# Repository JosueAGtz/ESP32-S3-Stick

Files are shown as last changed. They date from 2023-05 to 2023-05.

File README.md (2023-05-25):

# ESP32-S3 Stick

ESP32-S3 is a dual-core XTensa LX7 MCU, capable of running at 240 MHz. Apart from its 512 KB of internal SRAM, it also comes with integrated 2.4 GHz, 802.11 b/g/n Wi-Fi and Bluetooth 5 (LE) connectivity that provides long-range support. It has 45 programmable GPIOs and supports a rich set of peripherals.

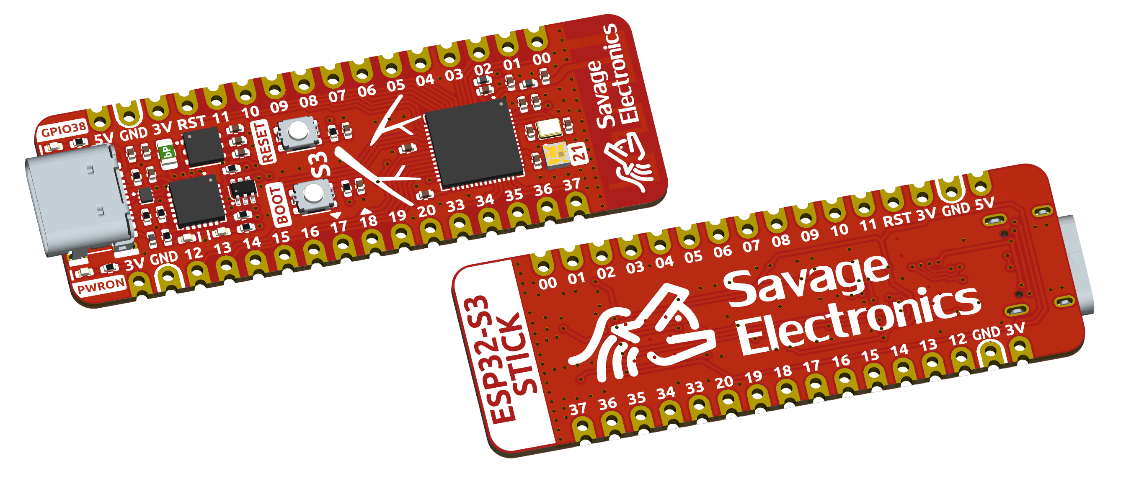
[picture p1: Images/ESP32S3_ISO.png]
ESP32S3_Board


## ESP32-S3 Stick Pinout

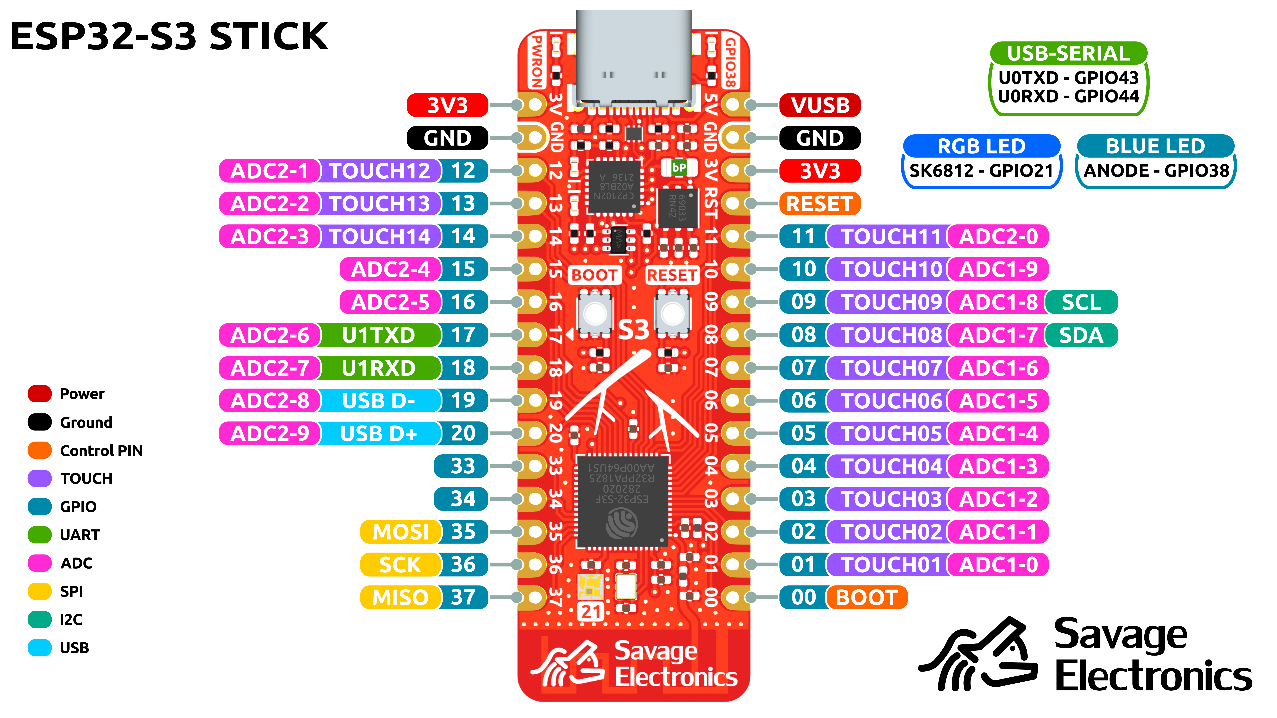
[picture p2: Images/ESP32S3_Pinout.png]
ESP32S3_Pinout


## ESP32-S3 Stick Features

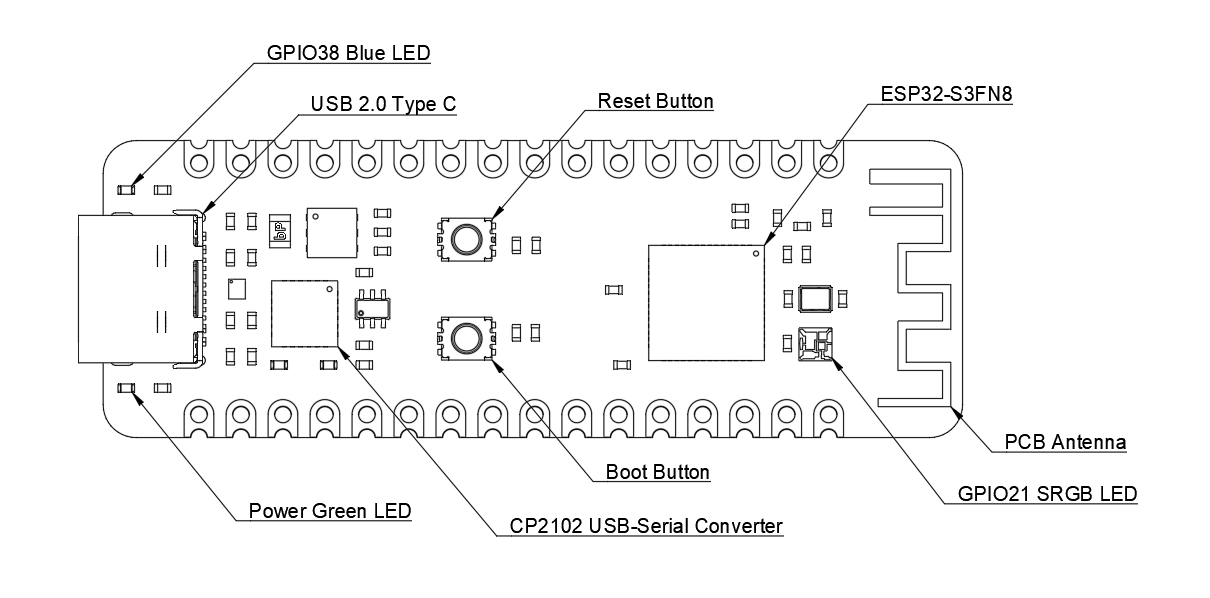
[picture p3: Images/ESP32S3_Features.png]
ESP32S3_Features


## ESP32-S3 Stick Dimmensions

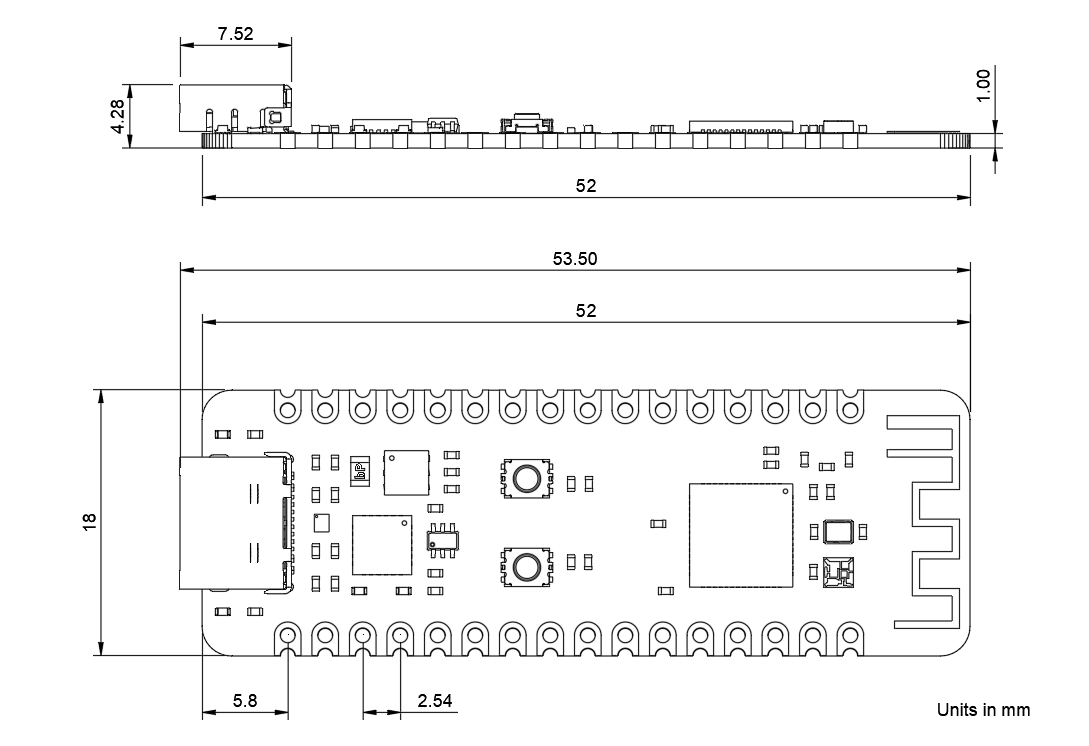
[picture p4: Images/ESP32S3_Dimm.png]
ESP32S3_Dimm


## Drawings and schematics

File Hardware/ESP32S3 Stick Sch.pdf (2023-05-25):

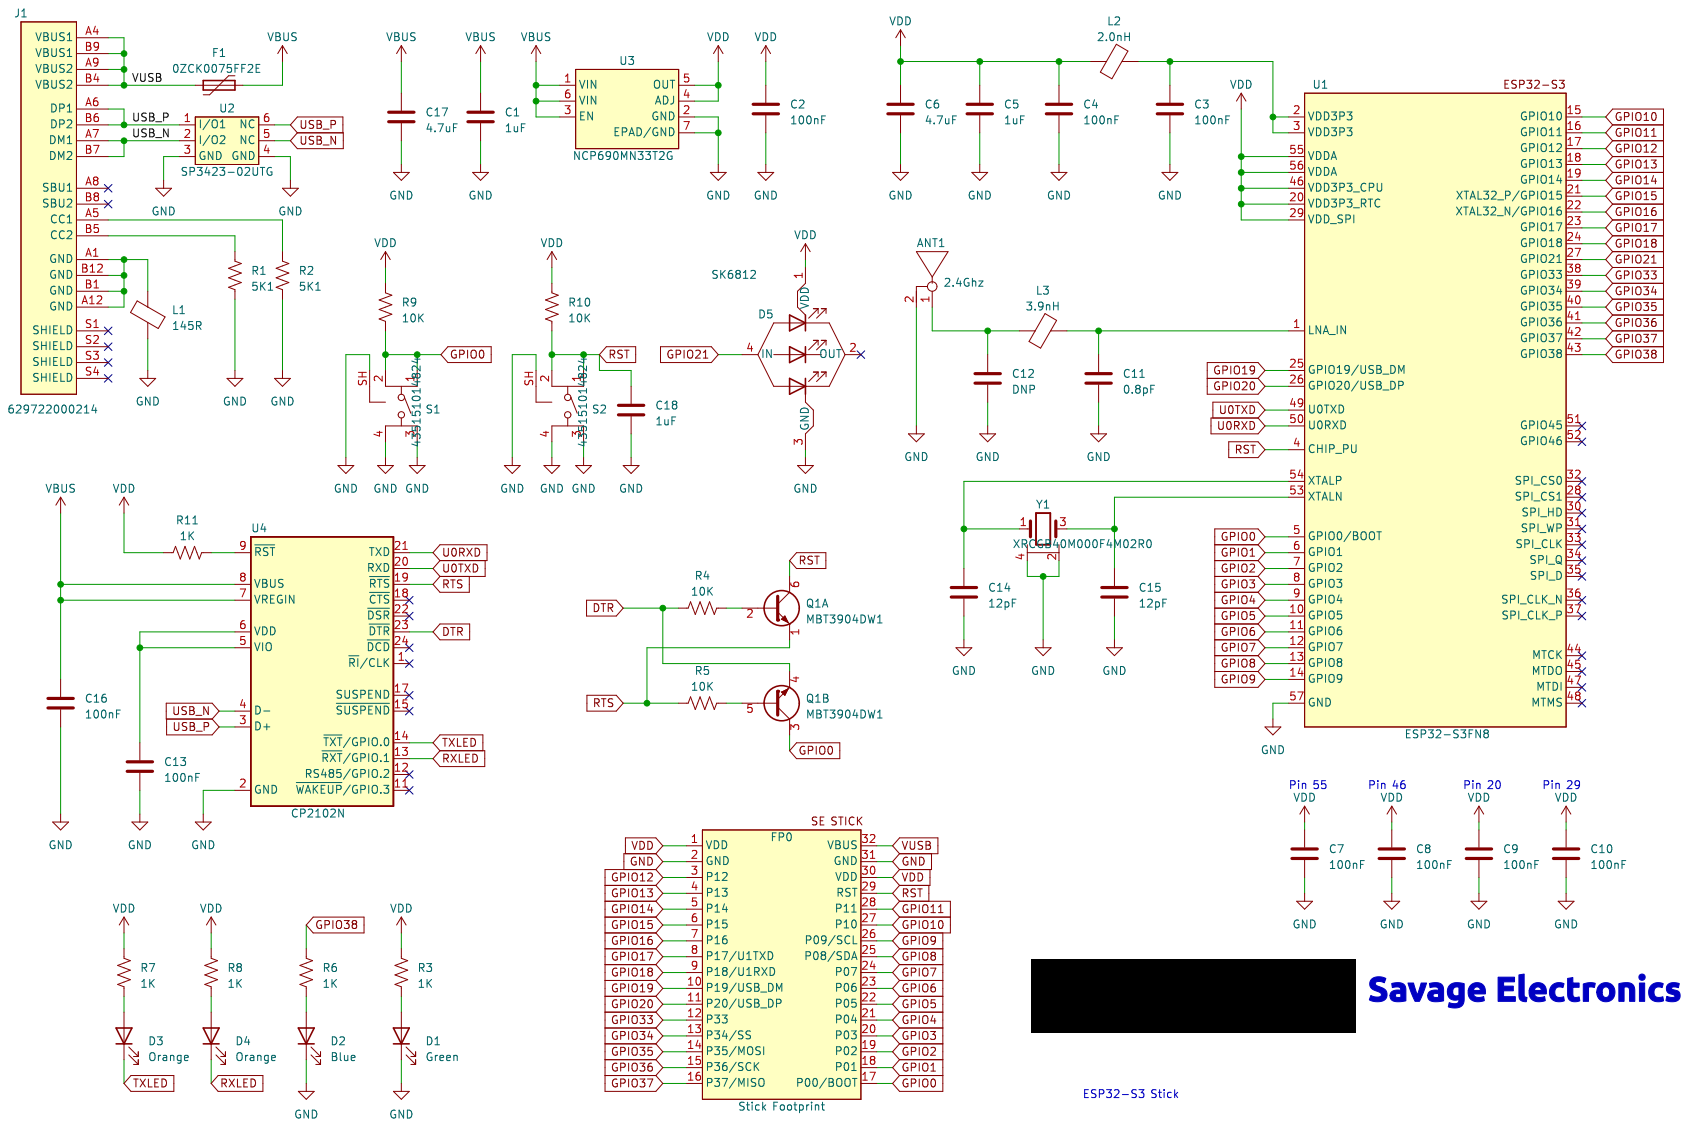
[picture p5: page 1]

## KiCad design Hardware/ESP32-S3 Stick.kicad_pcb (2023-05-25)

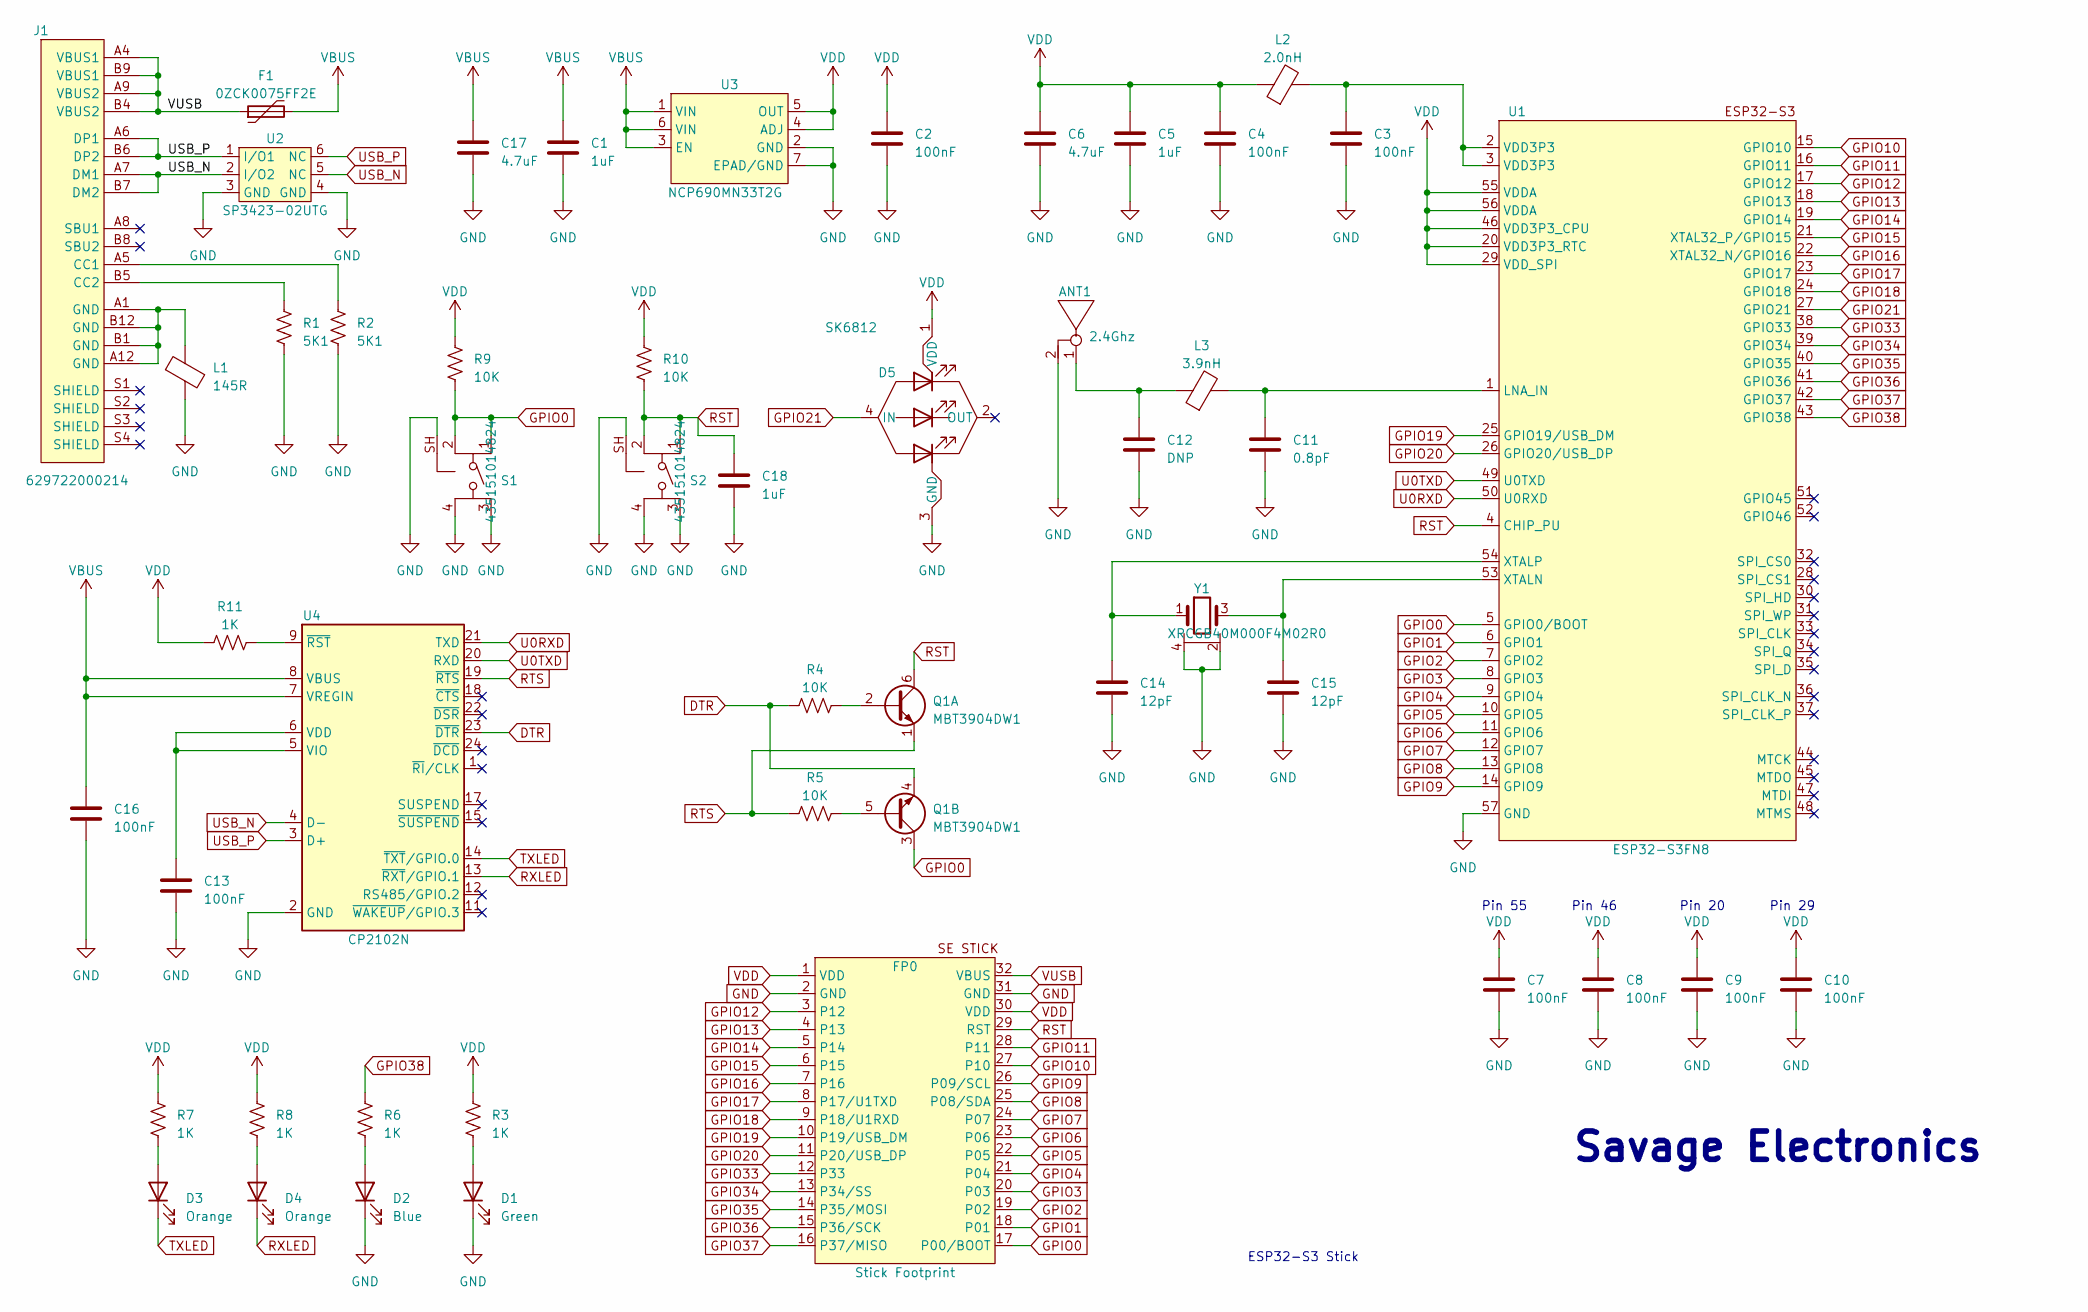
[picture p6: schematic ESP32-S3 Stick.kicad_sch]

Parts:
ANT1: 2.4Ghz; PCB_Ant24
C1, C5, C18: 1uF; C_0402_1005Metric
C2, C3, C4, C7, C8, C9, C10, C13, C16: 100nF; C_0402_1005Metric
C6, C17: 4.7uF; C_0402_1005Metric
C11: 0.8pF; C_0402_1005Metric
C12: DNP; C_0402_1005Metric
C14, C15: 12pF; C_0402_1005Metric
D1: Green; 0402LED
D2: Blue; 0402LED
D3, D4: Orange; 0402LED
D5: SK6812; SK6812_2X2mm
F1: 0ZCK0075FF2E; Fuse_0805_2012Metric
FP0: Stick Footprint; Stick
J1: 629722000214; USBC 2.0
L1: 145R; L_0402_1005Metric
L2: 2.0nH; L_0402_1005Metric
L3: 3.9nH; L_0402_1005Metric
Q1: MBT3904DW1; SC70_6P
R1, R2: 5K1; R_0402_1005Metric
R3, R6, R7, R8, R11: 1K; R_0402_1005Metric
R4, R5, R9, R10: 10K; R_0402_1005Metric
S1, S2: 435151014824
U1: ESP32-S3FN8; QFN-56-1EP_7x7mm_P0.4mm_EP4x4mm_ThermalVias_ ESP32-S3
U2: SP3423-02UTG
U3: NCP690MN33T2G; DFN6_P1MM_EP
U4: CP2102N; QFN24_4X4MM_P05_EP26
Y1: XRCGB40M000F4M02R0; SMD_4PADS_20X16

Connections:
DTR: Q1.4 (E2), R4.1, U4.23 (~DTR)
GND: ANT1.2, C1.2, C2.2, C3.2, C4.2, C5.2, C6.2, C7.2, C8.2, C9.2, C10.2, C11.2, C12.2, C13.2, C14.2, C15.2, C16.2, C17.2, C18.2, D1.1 (K), D2.1 (K), D5.3 (GND), FP0.2 (GND), FP0.31 (GND), L1.2, R1.2, R2.2, S1.3, S1.4, S1.SH, S2.3, S2.4, S2.SH, U1.57 (GND), U2.3 (GND), U2.4 (GND), U3.2 (GND), U3.7 (EPAD/GND), U4.2 (GND), U4.25 (GND), Y1.2, Y1.4
GPIO0: FP0.17 (P00/BOOT), Q1.3 (C2), R9.2, S1.1, S1.2, U1.5 (GPIO0/BOOT)
GPIO1: FP0.18 (P01), U1.6 (GPIO1)
GPIO2: FP0.19 (P02), U1.7 (GPIO2)
GPIO3: FP0.20 (P03), U1.8 (GPIO3)
GPIO4: FP0.21 (P04), U1.9 (GPIO4)
GPIO5: FP0.22 (P05), U1.10 (GPIO5)
GPIO6: FP0.23 (P06), U1.11 (GPIO6)
GPIO7: FP0.24 (P07), U1.12 (GPIO7)
GPIO8: FP0.25 (P08/SDA), U1.13 (GPIO8)
GPIO9: FP0.26 (P09/SCL), U1.14 (GPIO9)
GPIO10: FP0.27 (P10), U1.15 (GPIO10)
GPIO11: FP0.28 (P11), U1.16 (GPIO11)
GPIO12: FP0.3 (P12), U1.17 (GPIO12)
GPIO13: FP0.4 (P13), U1.18 (GPIO13)
GPIO14: FP0.5 (P14), U1.19 (GPIO14)
GPIO15: FP0.6 (P15), U1.21 (XTAL32_P/GPIO15)
GPIO16: FP0.7 (P16), U1.22 (XTAL32_N/GPIO16)
GPIO17: FP0.8 (P17/U1TXD), U1.23 (GPIO17)
GPIO18: FP0.9 (P18/U1RXD), U1.24 (GPIO18)
GPIO19: FP0.10 (P19/USB_DM), U1.25 (GPIO19/USB_DM)
GPIO20: FP0.11 (P20/USB_DP), U1.26 (GPIO20/USB_DP)
GPIO21: D5.4 (IN), U1.27 (GPIO21)
GPIO33: FP0.12 (P33), U1.38 (GPIO33)
GPIO34: FP0.13 (P34/SS), U1.39 (GPIO34)
GPIO35: FP0.14 (P35/MOSI), U1.40 (GPIO35)
GPIO36: FP0.15 (P36/SCK), U1.41 (GPIO36)
GPIO37: FP0.16 (P37/MISO), U1.42 (GPIO37)
GPIO38: R6.1, U1.43 (GPIO38)
unnamed: ANT1.1, C12.1, L3.1
unnamed: C3.1, L2.2, U1.2 (VDD3P3), U1.3 (VDD3P3)
unnamed: D1.2 (A), R3.2
unnamed: D2.2 (A), R6.2
unnamed: D3.2 (A), R7.2
unnamed: D4.2 (A), R8.2
unnamed: J1.A5 (CC1), R2.1
unnamed: J1.B5 (CC2), R1.1
unnamed: J1.A1 (GND), J1.A12 (GND), J1.B1 (GND), J1.B12 (GND), L1.1
unnamed: Q1.2 (B1), R4.2
unnamed: Q1.5 (B2), R5.2
unnamed: C11.1, L3.2, U1.1 (LNA_IN)
unnamed: C15.1, U1.53 (XTALN), Y1.3
unnamed: C14.1, U1.54 (XTALP), Y1.1
unnamed: C13.1, U4.5 (VIO), U4.6 (VDD)
unnamed: R11.2, U4.9 (~RST)
RST: C18.1, FP0.29 (RST), Q1.6 (C1), R10.2, S2.1, S2.2, U1.4 (CHIP_PU)
RTS: Q1.1 (E1), R5.1, U4.19 (~RTS)
RXLED: D4.1 (K), U4.13 (~RXT/GPIO.1)
TXLED: D3.1 (K), U4.14 (~TXT/GPIO.0)
U0RXD: U1.50 (U0RXD), U4.21 (TXD)
U0TXD: U1.49 (U0TXD), U4.20 (RXD)
USB_N: J1.A7 (DM1), J1.B7 (DM2), U2.2 (I/O2), U2.5 (NC), U4.4 (D-)
USB_P: J1.A6 (DP1), J1.B6 (DP2), U2.1 (I/O1), U2.6 (NC), U4.3 (D+)
VBUS: C1.1, C16.1, C17.1, F1.2, U3.1 (VIN), U3.3 (EN), U3.6 (VIN), U4.7 (VREGIN), U4.8 (VBUS)
VDD: C2.1, C4.1, C5.1, C6.1, C7.1, C8.1, C9.1, C10.1, D5.1 (VDD), FP0.1 (VDD), FP0.30 (VDD), L2.1, R3.1, R7.1, R8.1, R9.1, R10.1, R11.1, U1.20 (VDD3P3_RTC), U1.29 (VDD_SPI), U1.46 (VDD3P3_CPU), U1.55 (VDDA), U1.56 (VDDA), U3.4 (ADJ), U3.5 (OUT)
VUSB: F1.1, FP0.32 (VBUS), J1.A4 (VBUS1), J1.A9 (VBUS2), J1.B4 (VBUS2), J1.B9 (VBUS1)

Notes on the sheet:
Pin 55
Pin 29
ESP32-S3 Stick
Pin 20
Savage Electronics
Pin 46

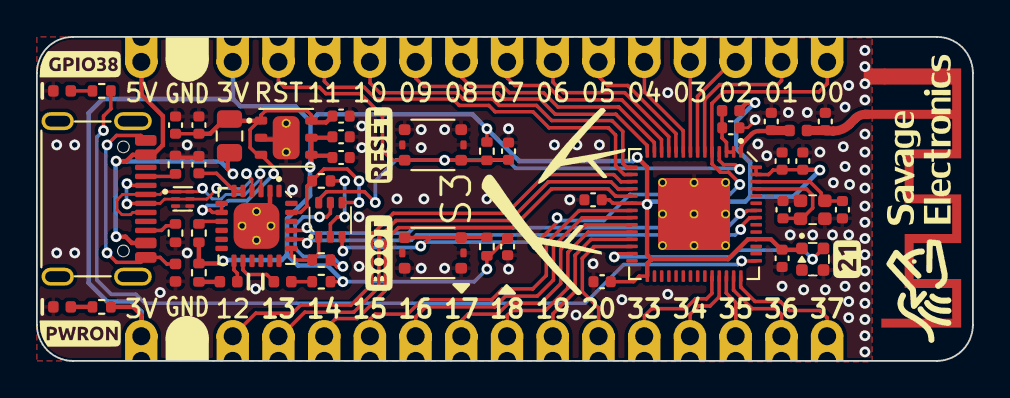
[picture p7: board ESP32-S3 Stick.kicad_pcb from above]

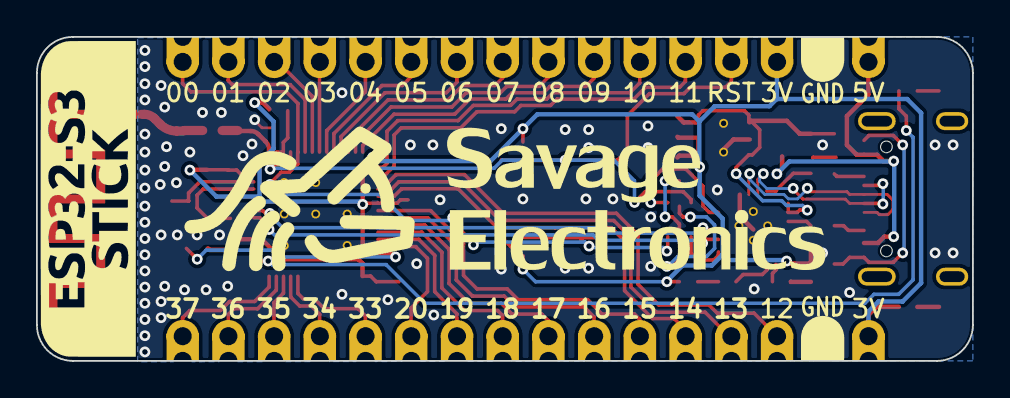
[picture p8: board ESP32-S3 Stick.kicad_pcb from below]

Board: 2 copper layers, 52.0 x 18.0 mm, 58 parts (2 on the bottom side), 57 nets.

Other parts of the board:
G_antennaLogo: LOGO; G_S3_ANT_LOGO
G_boot: LOGO; G_BOOT
G_gpio38: LOGO; G_GPIO38
G_logoSmall: LOGO; G_SELOGO_SMALL
G_neopixel: LOGO; G_NEOPIXEL
G_pwron: LOGO; G_PWRON
G_reset: LOGO; G_RESET
G_sticks: LOGO; G_STICKS
e: LOGO; G_SELOGO_MED
